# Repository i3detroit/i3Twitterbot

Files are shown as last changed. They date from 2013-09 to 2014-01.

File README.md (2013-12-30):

i3Twitterbot
============

Twitterbot!

Features
========
* Near-realtime switch status
* Countdown timer for picture grab
* Prominent on/off LEDs
* Twitter/Twitpic integration
* IRC integration
* Website integration

Requirements
============
* [tweepy](http://github.com/tweepy/tweepy)
	- setuptools
	- [py_compile](https://groups.google.com/forum/?fromgroups=#!topic/beaglebone/LU6LoEs-zHQ) (missing on the beaglebone Angstrom -.-)
* [oyoyo](https://code.google.com/p/oyoyo/)
* [py-spi](http://www.gigamegablog.com/2012/09/09/beaglebone-coding-101-spi-output/)
* [PyBBIO](https://github.com/alexanderhiam/PyBBIO)
* [ivy-python](http://www.eei.cena.fr/products/ivy/download/checkouts.html)
* [paramiko](https://github.com/paramiko/paramiko/)

Usage
=====
0. Have beaglebone running Angstrom with custom cape and hardware.
1. Edit `twitterbot.ini.example` for your installation parameters.
2. Make sure to rename `twitterbot.ini.example` to `twitterbot.ini`.
3. Start up `manager.py`, which should start up all the other agents.

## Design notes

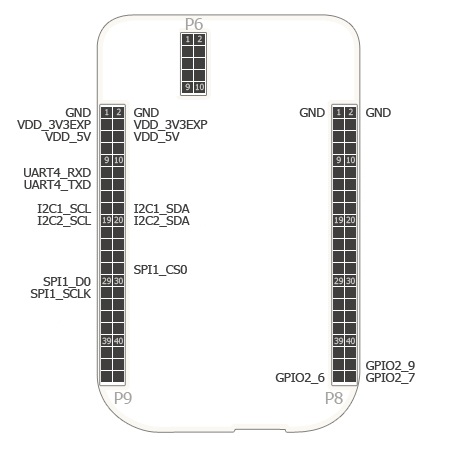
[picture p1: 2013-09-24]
board/PinDiagram.jpg

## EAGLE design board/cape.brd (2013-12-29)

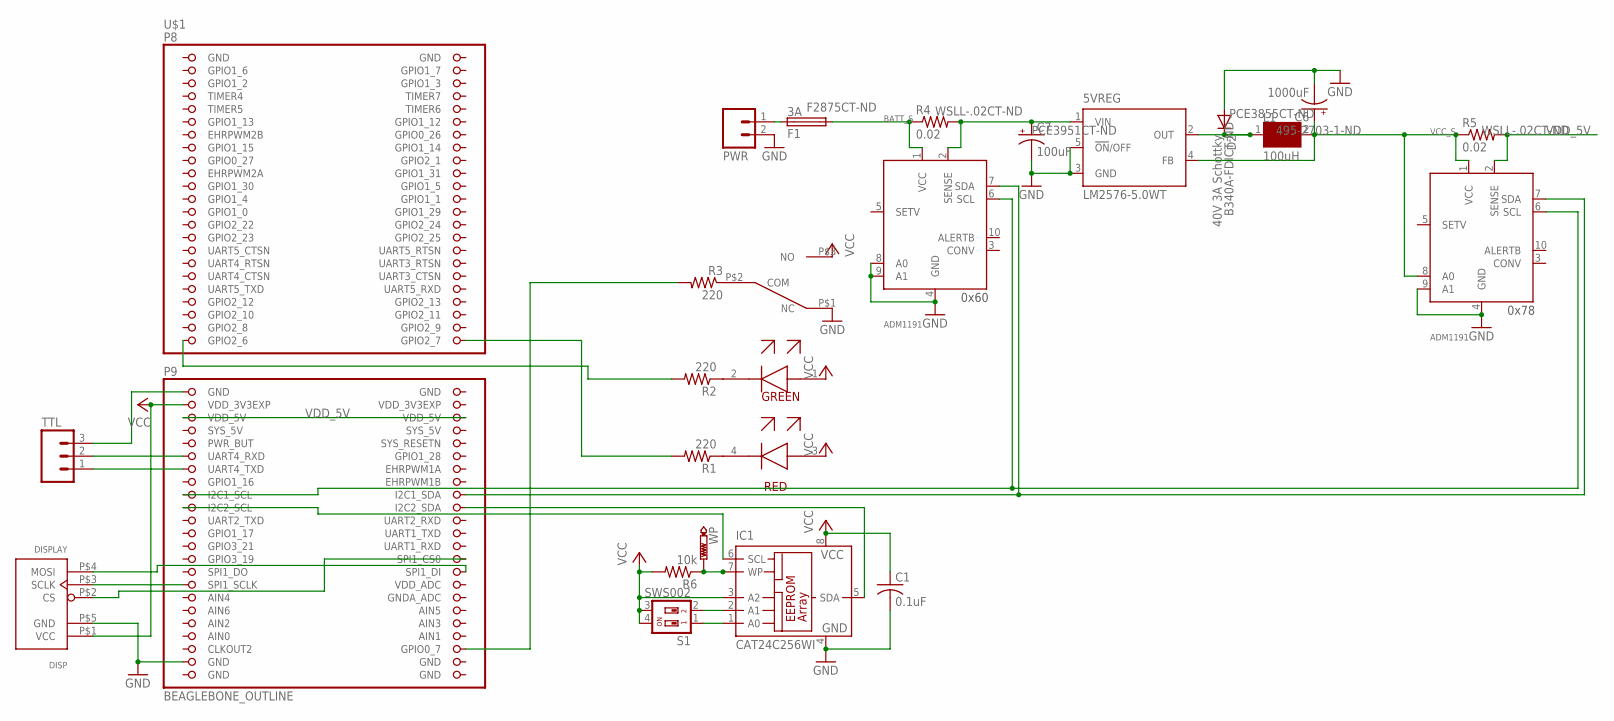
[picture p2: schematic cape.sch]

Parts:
5VREG: LM2576-5.0WT; TO263-5
BATT_S: ADM1191; MSOP-10
C1: 0.1uF; C0603
C6: 1000uF; 175TMP-0808; DIGIKEY PCE3855CT-ND
C7: 100uF; 153CLV-0605; DIGIKEY PCE3951CT-ND
D2: 40V 3A Schottky; DO-214AC; DIGIKEY B340A-FDICT-ND
DISP: DISPLAY; 1X6
F1: 3A; 2920; DIGIKEY F2875CT-ND
IC1: CAT24C256WI; SO-08
L1: 100uH; INDUCTOR; DIGIKEY 495-2703-1-ND
PWR: M025MM; SCREWTERMINAL-5MM-2
R1, R2, R3: 220; R0603
R4, R5: 0.02; R0603; DIGIKEY WSLL-.02CT-ND
R6: 10k; R0603
S1: SWS002; SMS-002
TTL: M03LOCK; 1X03_LOCK
U$1: BEAGLEBONE_OUTLINE; BEAGLEBONE_SHIELD
U$2: LEDS; 2X2
U$3: SWITCH; 1X3
VCC_S: ADM1191; MSOP-10
WP: PTR1TP10R; TP10R

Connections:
12VDC: F1.1, PWR.1
12V_FUSE: 5VREG.1 (VIN), BATT_S.2 (SENSE), C7.+, R4.2
AIN0: U$1.85 (AIN0)
CS: DISP.P$2 (CS), U$1.74 (SPI1_CS0)
GND: 5VREG.3 (GND), 5VREG.5 (!ON!/OFF), BATT_S.4 (GND), BATT_S.8 (A0), BATT_S.9 (A1), C1.2, C6.-, C7.-, D2.A, DISP.P$5 (GND), IC1.4 (GND), PWR.2, TTL.3, U$1.1 (GND), U$1.2 (GND), U$1.47 (GND), U$1.48 (GND), U$1.89 (GND), U$1.90 (GND), U$1.91 (GND), U$1.92 (GND), U$3.P$1 (NC), VCC_S.4 (GND), VCC_S.9 (A1)
GRN_LED: R2.2, U$1.45 (GPIO2_6)
I2C1_SCL: BATT_S.6 (SCL), U$1.63 (I2C1_SCL), VCC_S.6 (SCL)
I2C1_SDA: BATT_S.7 (SDA), U$1.64 (I2C1_SDA), VCC_S.7 (SDA)
I2C2_SCL: IC1.6 (SCL), U$1.65 (I2C2_SCL)
I2C2_SDA: IC1.5 (SDA), U$1.66 (I2C2_SDA)
unnamed: R1.1, U$2.4
unnamed: R2.1, U$2.2
unnamed: R3.1, U$3.P$2 (COM)
unnamed: DISP.P$4 (MOSI), U$1.76 (SPI1_DI)
unnamed: 5VREG.2 (OUT), D2.C, L1.1
unnamed: BATT_S.1 (VCC), F1.2, R4.1
unnamed: IC1.1 (A0), S1.1
unnamed: IC1.2 (A1), S1.2
unnamed: 5VREG.4 (FB), C6.+, L1.2, R5.1, VCC_S.1 (VCC), VCC_S.8 (A0)
unnamed: IC1.7 (WP), R6.1, WP.TP
RED_LED: R1.2, U$1.46 (GPIO2_7)
RXI: TTL.2, U$1.57 (UART4_RXD)
SCLK: DISP.P$3 (SCLK), U$1.77 (SPI1_SCLK)
SW: R3.2, U$1.88 (GPIO0_7)
SYS_5V: U$1.53 (SYS_5V)
TXO: TTL.1, U$1.59 (UART4_TXD)
VCC: C1.1, DISP.P$1 (VCC), IC1.3 (A2), IC1.8 (VCC), R6.2, S1.3, S1.4, U$1.49 (VDD_3V3EXP), U$2.1, U$2.3, U$3.P$3 (NO)
VDD_3V3EXP: U$1.50 (VDD_3V3EXP)
VDD_5V: R5.2, U$1.51 (VDD_5V), U$1.52 (VDD_5V), VCC_S.2 (SENSE)

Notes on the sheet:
0x78
0x60

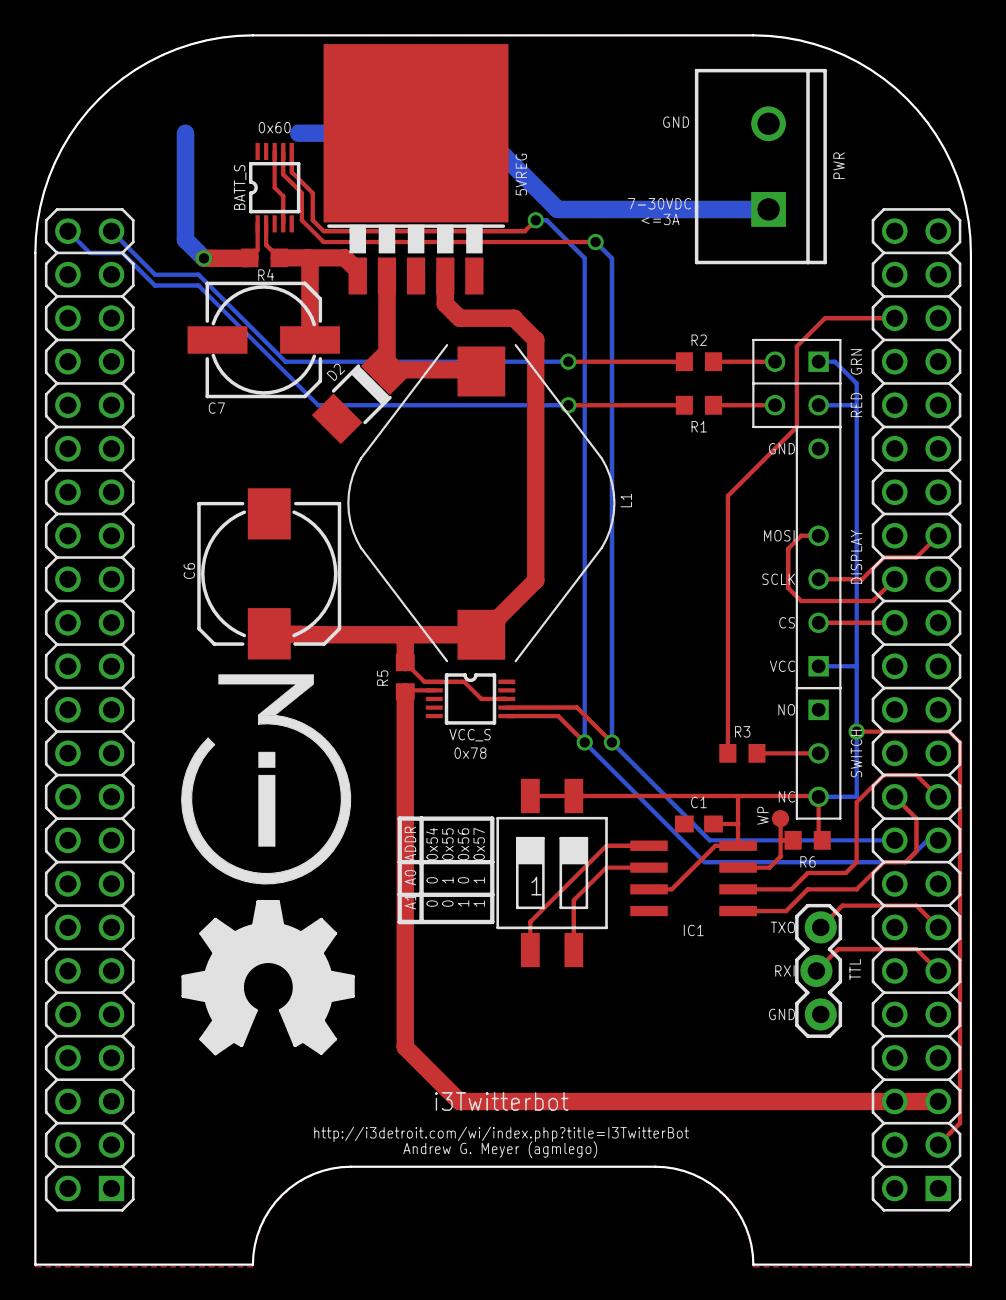
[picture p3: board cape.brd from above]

Board: 2 copper layers, 54.6 x 71.8 mm, 25 parts (1 on the bottom side), 26 nets.

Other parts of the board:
U$4: OSHW_FILLX350_NOTEXT

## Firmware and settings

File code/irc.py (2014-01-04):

#!/usr/bin/env python
from oyoyo.client import IRCClient
from oyoyo.parse import *
from oyoyo.cmdhandler import DefaultCommandHandler
from oyoyo import helpers
from random import choice
from ivy.std_api import *
import string
import sys
import logging
import logging.config
from ConfigParser import SafeConfigParser

logging.config.fileConfig('conf/twitterbot.log.ini')
irclogger = logging.getLogger('Twitterbot.IRC')

HOST = None
PORT = None
NICK = None
NAME = None
IDENT = None
CHANS = None
TOPIC_CHANS = None
AUTHD = None

state = -1
cli = None
curtopic = ''

greetings = ['Hello','Hi','Good morning','Good afternoon','Good evening','Hey']

help_msg = {
'status':'Prints out the current state of the space',
'join':'Causes the bot to join a channel',
'part':'Causes the bot to part from a channel',
'announce':'Adds the channel given to the list in which status changes are announced',
'deannounce':'Removes the channel given from the list in which status changes are announced',
'op':'Adds a nick to the authorized operators list',
'deop':'Removes a nick from the authorized operators list',
'die':'Kills the bot',
'help':'Provides help on commands',
}

def state_text(state):
    return ('not responding','CLOSED','OPEN')[state+1]

def authed(self,nick,chan):
    isauth = nick in AUTHD
    if not isauth:
        helpers.msg(self.client,chan,'%s: You are not authorized to do that'%nick)
    return isauth

def die(self,nick,chan,msg):
    global cli
    if authed(self,nick,chan):
        IvyStop()
        sys.exit()

def help_cmd(self,nick,chan,msg):
    if msg == '':
        helpers.msg(self.client,chan,'%s: I can help with %s'%(nick,', '.join(commands.keys())))
    elif msg in commands.keys():
        helpers.msg(self.client,chan,'%s: "%s" -- %s'%(nick,msg,help_msg[msg]))
    else:
        helpers.msg(self.client,chan,'%s: I am a program with limited response capabilities. "%s" is not a command I can help you with. Try asking the right question.'%(nick,msg))

def status(self,nick,chan,msg):
    helpers.msg(self.client,chan,'%s: The space is %s'%(nick,state_text(state)))

def add_op(self,nick,chan,msg):
    if authed(self,nick,chan):
        if msg not in AUTHD:
            AUTHD.append(msg)
            config.set('IRC','authed_users',','.join(AUTHD))
            helpers.msg(self.client,chan,'%s: OK, I added %s as a bot operator'%(nick,msg))
        elif msg == nick:
            helpers.msg(self.client,chan,'%s: Um...you already are an operator...'%(nick))
        else:
            helpers.msg(self.client,chan,'%s: Um...%s is *already* a bot operator...'%(nick,msg))
        

def del_op(self,nick,chan,msg):
    if authed(self,nick,chan):
        if msg in AUTHD:
            AUTHD.remove(msg)
            config.set('IRC','authed_users',','.join(AUTHD))
            helpers.msg(self.client,chan,'%s: OK, I removed %s as a bot operator'%(nick,msg))
        else:
            helpers.msg(self.client,chan,'%s: Um...%s is not a bot operator...'%(nick,msg))

def join(self,nick,chan,msg):
    if authed(self,nick,chan):
        if msg not in CHANS:
            CHANS.append(msg)
            config.set('IRC','channels',','.join(CHANS))
            helpers.join(cli, msg)
            helpers.msg(self.client,chan,'%s: OK, I joined %s'%(nick,msg))
        elif msg == chan:
            helpers.msg(self.client,chan,'%s: Um...this *is* %s...'%(nick,msg))
        else:
            helpers.msg(self.client,chan,'%s: Um...I am *already* in %s...'%(nick,msg))

def part(self,nick,chan,msg):
    if authed(self,nick,chan):
        if msg in CHANS:
            CHANS.remove(msg)
            config.set('IRC','channels',','.join(CHANS))
            helpers.part(cli, msg)
            helpers.msg(self.client,chan,'%s: OK, I parted %s'%(nick,msg))
        else:
            helpers.msg(self.client,chan,'%s: Um...I am not in %s...'%(nick,msg))

def announce(self,nick,chan,msg):
    if authed(self,nick,chan):
        if msg not in TOPIC_CHANS:
            TOPIC_CHANS.append(msg)
            config.set('IRC','announce',','.join(TOPIC_CHANS))
            helpers.msg(self.client,chan,'%s: OK, I will announce status changes in %s'%(nick,msg))
        else:
            helpers.msg(self.client,chan,'%s: Um...I am *already* announcing status changes in %s...'%(nick,msg))

def deannounce(self,nick,chan,msg):
    if authed(self,nick,chan):
        if msg in TOPIC_CHANS:
            TOPIC_CHANS.remove(msg)
            config.set('IRC','announce',','.join(TOPIC_CHANS))
            helpers.msg(self.client,chan,'%s: OK, I will stop announcing status changes in %s'%(nick,msg))
        else:
            helpers.msg(self.client,chan,'%s: Um...I am not announcing status changes in %s...'%(nick,msg))

commands = {
'status':status,
'join':join,
'part':part,
'announce':announce,
'deannounce':deannounce,
'op':add_op,
'deop':del_op,
'die':die,
'help':help_cmd,
}

def status_change(agent, status):
    global state
    global cli
    global curtopic
    status = int(status)
    ns = state_text(status)
    os = state_text(state)
    for chan in TOPIC_CHANS:
        if 'The space is' in curtopic:
            if os not in curtopic:
                start = curtopic.find('The space is ') + 13
                end = curtopic.find(' ',start)
                newtopic = curtopic[:start] + ns + curtopic[end:]
            else:
                newtopic = curtopic.replace(os,ns)
            cli.send('TOPIC',chan,':%s'%newtopic)
        else:
            helpers.msg(cli,chan,'The space is %s'%ns)
    irclogger.info('Space went from %s to %s, according to %r'%(os,ns,agent))
    state = status

def connect_callback(cli):
    if IDENT:
        irclogger.debug('Identifying with %s.'%IDENT)
        helpers.identify(cli,IDENT)
    else:
        irclogger.debug('NOT identifying')
    helpers.user(cli,NICK,NAME)
    for CHAN in CHANS:
        helpers.join(cli, CHAN)

def oncxproc(agent, connected):
    if connected == IvyApplicationDisconnected :
        irclogger.warning('Ivy application %r was disconnected', agent)
    else:
        irclogger.info('Ivy application %r was connected', agent)
    irclogger.debug('Current Ivy applications are [%s]', IvyGetApplicationList())

def ondieproc(agent, id):
    irclogger.warning('Received the order to die from %r with id = %d', agent, id)

def heartbeat(agent):
    IvySendMsg('hb_ack')

class MyHandler(DefaultCommandHandler):
    def privmsg(self, nick, chan, msg):
        if NICK in msg:
            n = nick[:nick.find('!')]
            irclogger.info('%s wants to talk with me!'%n)
            cmd = msg.replace(NICK,'').replace(':','').strip()
            idx = cmd.find(' ')
            if idx != -1:
                arg = cmd[cmd.find(' ')+1:]
                idx = cmd[:cmd.find(' ')]
            else:
                idx = cmd
                arg = ''
            if idx.lower() in commands.keys():
                commands[idx.lower()](self,n,chan,arg)
            elif ''.join([c for c in cmd if c in string.letters+' ']) in greetings:
                helpers.msg(self.client,chan,'%s: %s!'%(n,choice(greetings)))
            elif cmd.startswith('help'):
                help_cmd(self,n,chan,cmd.replace('help','').strip())
            else:
                helpers.msg(self.client,chan,'%s: "%s" is not a command I recognize. I can respond cordially to greetings, or to any of these commands: %s'%(n,cmd,', '.join(commands.keys())))
        irclogger.info("%s in %s said: %s" % (nick, chan, msg))

    def topic(self,user,channel,topic):
        global curtopic
        curtopic = topic
        irclogger.info('Topic by %s in %s is (%s) '\
                       %(user,channel,topic))

    def currenttopic(self,server,nick,channel,topic):
        global curtopic
        curtopic = topic
        irclogger.info('Topic for %s on %s is (%s) '
                       '[%s]'%(channel,server,topic,nick))

if __name__ == "__main__":
    config = SafeConfigParser({'identify':None})
    config.read('conf/twitterbot.ini')
   
    ivy_name = config.get('IRC','ivy_name')
    IvyInit(ivy_name,'[%s is ready]'%ivy_name,0,oncxproc,ondieproc)
    IvyStart(config.get('General','ivy_bus'))
    IvyBindMsg(status_change,'^status=(-?[0-1])')
    IvyBindMsg(heartbeat,'^hb_syn')
    IvySendMsg('status?')

    irclogger.setLevel(level=getattr(logging,config.get('IRC','log_level')))

    HOST = config.get('IRC','server')
    PORT = int(config.get('IRC','port'))
    NICK = config.get('IRC','nick')
    NAME = config.get('IRC','name')
    IDENT = config.get('IRC','identify')
    CHANS = config.get('IRC','channels').split(',')
    TOPIC_CHANS = config.get('IRC','announce').split(',')
    AUTHD = config.get('IRC','authed_users').split(',')

    cli = IRCClient(MyHandler, host=HOST, port=PORT, nick=NICK,
                connect_cb=connect_callback)
    conn = cli.connect()
    while True:
        conn.next()

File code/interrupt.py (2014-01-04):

#!/usr/bin/env python
# GPIO2_6 is green (open) LED, active low
# GPIO2_7 is red (closed) LED, active low
# GPIO0_9 is switch, low for open
from bbio import *
from ivy.std_api import *
import logging
import logging.config
import time
from datetime import datetime, timedelta
from ConfigParser import SafeConfigParser
from termcolor import cprint

logging.config.fileConfig('conf/twitterbot.log.ini')
hwlogger = logging.getLogger('Twitterbot.hardware')

GREEN_LED = GPIO2_6
RED_LED = GPIO2_7
SWITCH = GPIO0_7
DEBOUNCE = 200
DWELL = 2000

interested = None

state = -1

def oncxproc(agent, connected):
    if connected == IvyApplicationDisconnected :
        hwlogger.warning('Ivy application %r was disconnected', agent)
    else:
        name = agent.agent_name
        hwlogger.info('Ivy application %r was connected (name=%s)'%(agent,name))
        if name in interested and state != -1:
            IvySendMsg('status=%1d'%state)
            hwlogger.info('%r is interested in updates.'%agent)
    hwlogger.debug('Current Ivy applications are [%s]', IvyGetApplicationList())

def ondieproc(agent, id):
    hwlogger.warning('Received the order to die from %r with id = %d', agent, id)

def status_req(agent):
    hwlogger.info('%s requested status.'%agent)
    IvySendMsg('status=%1d'%state)

def led_change():
    global state
    if not hasattr(led_change,'oldstate'):
        led_change.oldstate = -1
        led_change.oldtime = datetime.min
    state = digitalRead(SWITCH)
    if led_change.oldstate != state:
        if(datetime.now() - led_change.oldtime) > timedelta(milliseconds=DEBOUNCE):
            if(datetime.now() - led_change.oldtime) < timedelta(milliseconds=DWELL):
                hwlogger.info('Rate-limiting...')
            else:
                hwlogger.info('The space is %s'%('OPEN','CLOSED')[state])
                digitalWrite(GREEN_LED, state)
                digitalWrite(RED_LED, not state)
                led_change.oldstate = state
                led_change.oldtime = datetime.now()
                IvySendMsg('status=%1d'%(1-state))

def heartbeat(agent):
    IvySendMsg('hb_ack')

def setup():
    pinMode(GREEN_LED, OUTPUT)
    pinMode(RED_LED, OUTPUT)
    pinMode(SWITCH, INPUT)
    attachInterrupt(SWITCH,led_change,BOTH)
    state = digitalRead(SWITCH)
    led_change()

def loop():
    time.sleep(1.0)

if __name__ == "__main__":
    config = SafeConfigParser()
    config.read('conf/twitterbot.ini')
   
    ivy_name = config.get('Hardware','ivy_name')
    IvyInit(ivy_name,'[%s is ready]'%ivy_name,0,oncxproc,ondieproc)
    IvyStart(config.get('General','ivy_bus'))
    IvyBindMsg(status_req,'^status\?')
    IvyBindMsg(heartbeat,'^hb_syn')
    hwlogger.setLevel(level=getattr(logging,config.get('Hardware','log_level')))
    DEBOUNCE = int(config.get('Hardware','debounce'))
    DWELL = int(config.get('Hardware','dwell'))
    interested = []
    for client in config.get('Hardware','interested').split(','):
        interested.append(config.get(client,'ivy_name'))
    print interested
    run(setup, loop)

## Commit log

2013-06-13 Added driver for PT6961 controller on 4-digt seven-segment display, using py-spi. Does not seem to work yet...
2013-06-13 Debugging...py-spi does not actually accomplish lsbfirst successfully
2013-06-30 Switching from phenny to oyoyo.
2013-07-06 Added board files, moved code to subdirectory.
    [cape.brd, cape.sch]
2013-07-06 Added code example to pull JPG data off IP camera.
2013-07-07 Finished schematic and routing.
    [cape.brd, cape.sch]
2013-07-07 Moved items on tDocu to _tsilk for OSHPark.
    [cape.brd]
2013-07-07 Added project information and logos to board.
    [cape.brd]
2013-07-08 Moved i3 logo to _tsilk after tracing by hand...hopefully it shows up in OSHPark now.
    [cape.brd]
2013-09-24 Added code for interrupt-based switch response and LED control.
2013-09-24 Moved hardware stuff into code directory. Added cape-specific information.
    [CapeRegistration.xlsx]
2013-09-26 Initial draft of tweepy-powered update script. Modeled after the IRC module, but with Twitter updates instead of channel announcements.
2013-09-26 Renamed twitter module to avoid name collision with tweepy module.
    [twitter.py]
2013-11-01 Syntax fixes and style
    [interrupt.py, irc.py]
2013-12-28 Changed switch pin due to conflicts with boot-configuration pins.
2013-12-29 Fixed failures to send status changes to Ivy bus, agent name/interested parties list.
    [interrupt.py]
2013-12-29 Added bash file to mux UART4 correctly for OAC interface.
2013-12-29 Altered board to as-built greenwiring, fixing confusion on SPI1_D0/SPI1_D1 and moving the switch from a necessary boot-configuration pin to a free one.
    [cape.brd, cape.sch]
2013-12-30 Added agent for website update. Currently uses SFTP to push a file to be included by hacky Wordpress/PHP script. Should use SpaceAPI or similar; later project.
2013-12-30 Added sample INI file for configuartion.
2013-12-30 Added camera functionality. Image will be pushed to same webserver as space-status file for hacky Wordpress/PHP script to grab. Hello, Internet\!
2013-12-30 Added camera to list of interested agents in switch notices.
2013-12-30 Added countdown to camera.
2013-12-30 Finalised fixes before rollout.
    [PT6961.py, cam.py, interrupt.py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]
2013-12-31 Added rate-limiting to interrupt.py, closing #1
2013-12-31 Added image-upload capability to Twitter agent, resolves #2.
    [twitter.py]
2013-12-31 Added manager.py script, resolves #5.
    [cam.py, interrupt.py, irc.py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]
2013-12-31 Fixed crash bug in twitter.py
    [twitter.py]
2014-01-04 irc.py now checks in announce channels to see if it can change the topic instead of announcing in-band. Added logic for agents to poll interrupt.py for switch state. Resolves #7.
    [cam.py, interrupt.py, irc.py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]
2014-01-04 Fixed initialisation routines for switch status.
    [interrupt.py, irc.py]

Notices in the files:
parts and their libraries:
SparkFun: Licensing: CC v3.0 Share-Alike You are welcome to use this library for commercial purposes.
